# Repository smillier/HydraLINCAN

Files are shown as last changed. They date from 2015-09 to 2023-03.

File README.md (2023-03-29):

# HydraLINCAN shield for HydraBus

CAN and LIN Bus shield for Hydrabus http://hydrabus.com/
Refer to Hydrabus Wiki for more information on usage. https://github.com/hydrabus/hydrafw/wiki/HydraFW-CAN-guide



#### New version with cleaner and easier to read silkscreen.

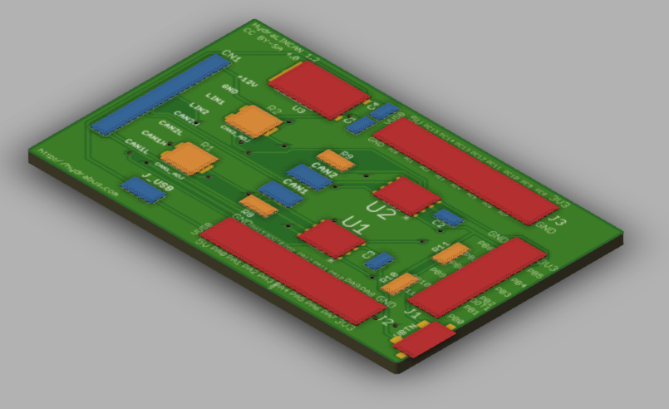
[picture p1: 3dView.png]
3DPreview


Here is the wiring schema for HydraLINCAN.

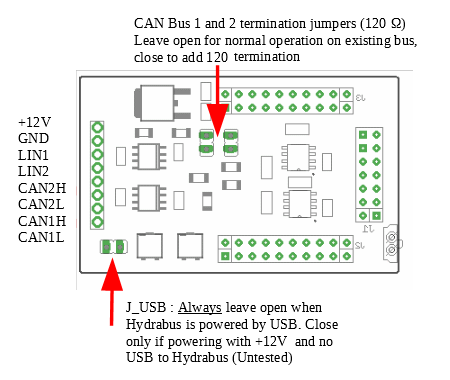
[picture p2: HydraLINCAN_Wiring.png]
HydraLINCANWiring


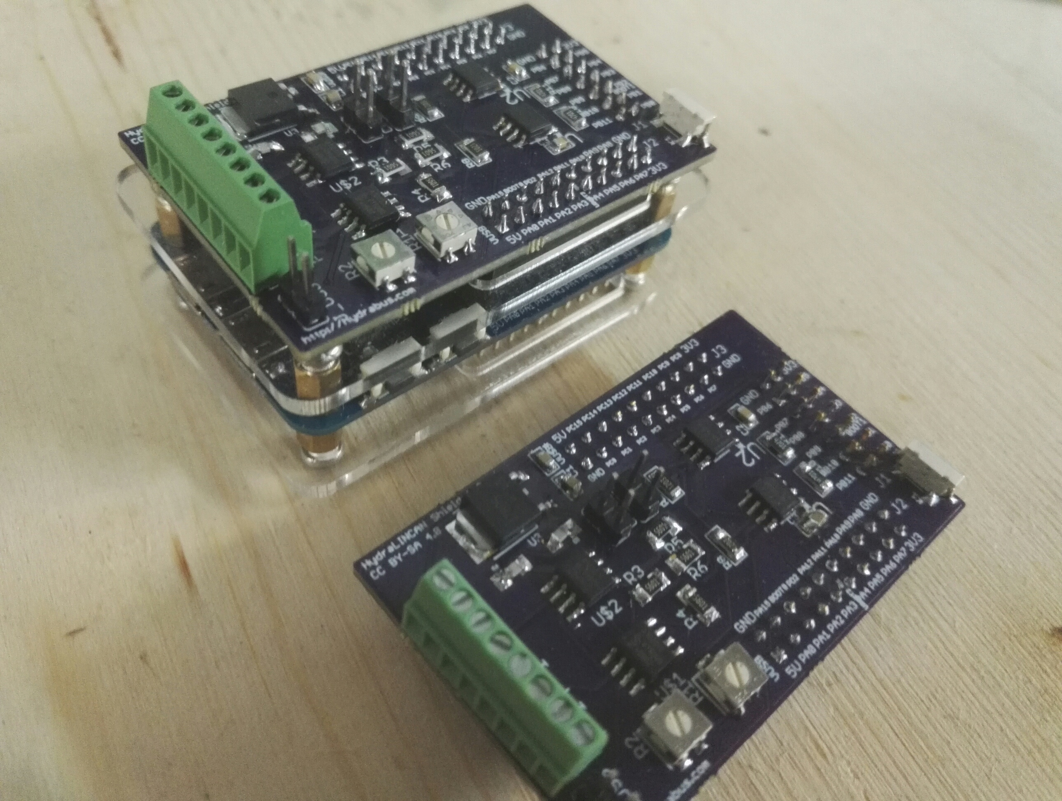
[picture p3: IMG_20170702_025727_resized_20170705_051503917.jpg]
HydraCAN


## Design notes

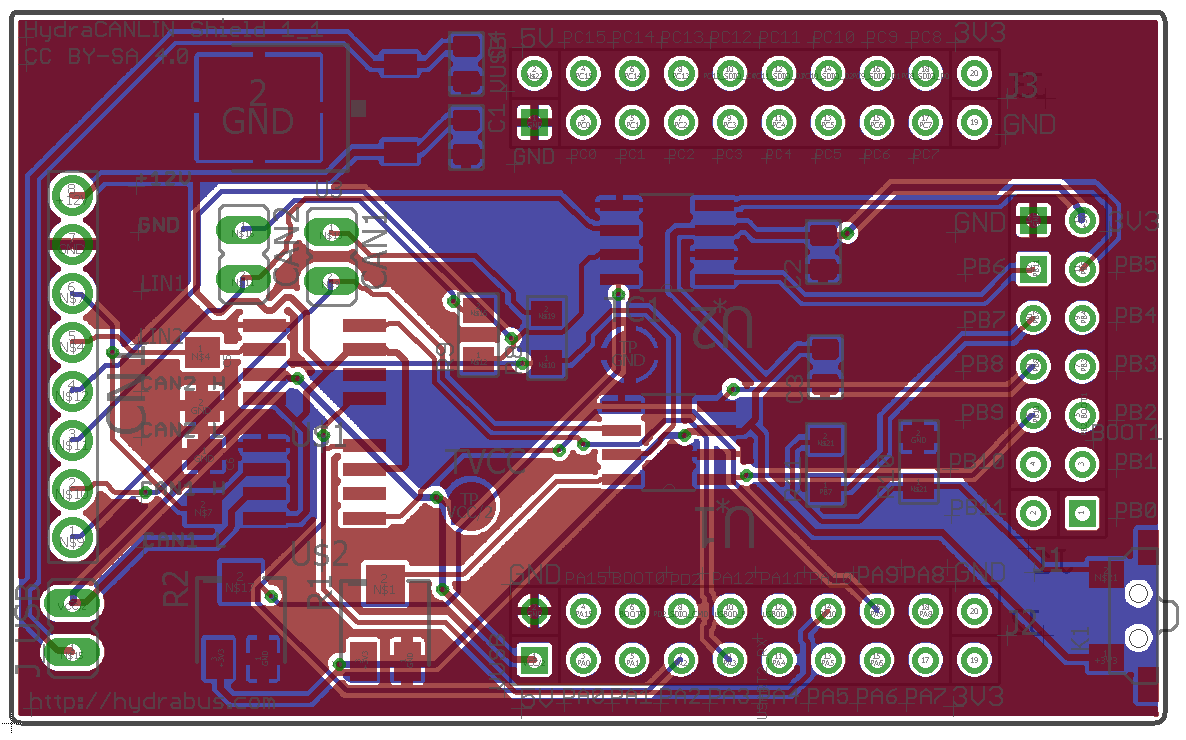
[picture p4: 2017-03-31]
HydraLINCAN.PNG

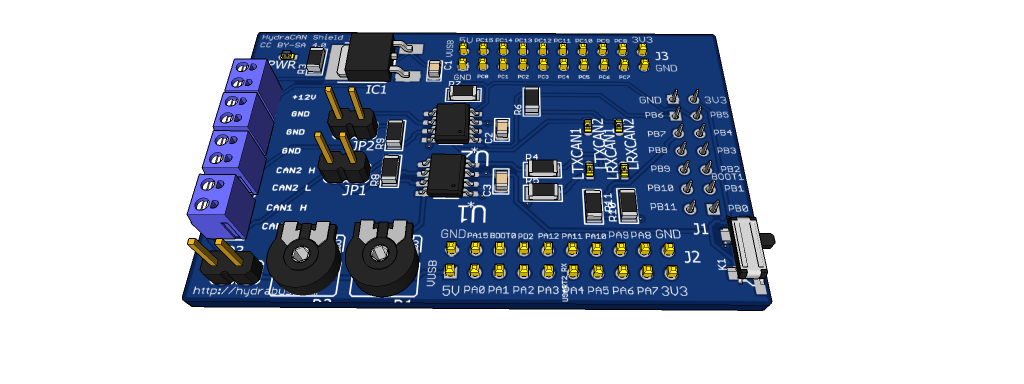
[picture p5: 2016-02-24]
hydraCanShield.png

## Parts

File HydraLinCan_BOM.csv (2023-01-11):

Part | Desc | Mouser | Digikey | LCSC
J1 | Header f2*7 | 855-M20-7830746 | S9197-ND | C124424
J2 | Header F2*10 | M20-7831046 | S9195-ND | C30867
J3 | Header F2*10 | M20-7831046 | S9195-ND | C30867
U1 | CAN SN65HVD233DG4 | 595-SN65HVD233DG4 | 296-35967-1-ND | C61643
U2 | CAN SN65HVD233DG4 | 595-SN65HVD233DG4 | 296-35967-1-ND | C61643
LIN1 | LIN TJA1021 | 771-TJA1021T10CM118 | 568-4643-1-ND | C128810
LIN2 | LIN TJA1021 | 771-TJA1021T10CM118 | 568-4643-1-ND | C128810
CN1 | Screw terminal 8p | 651-1725711 | ED10566-ND | C350883
R1 | 100K Trimmer | 652-3314J-1-104E | 3314G-104ETR-ND | C51284
R2 | 100K Trimmer | 652-3314J-1-104E | 3314G-104ETR-ND | C51284
U3 | VReg 5V | MC7805CDTG | MC7805BDTGOS-ND | C83632
R3 | R1206 4K7 | 603-RC1206FR-074K7L | CR1206-JW-472ELFCT-ND | C137262
R4 | R1206 4K7 | 603-RC1206FR-074K7L | CR1206-JW-472ELFCT-ND | C137262
R5 | R1206 4K7 | 603-RC1206FR-074K7L | CR1206-JW-472ELFCT-ND | C137262
R6 | R1206 4K7 | 603-RC1206FR-074K7L | CR1206-JW-472ELFCT-ND | C137262
R8 | R1206 120K | 667-ERJ-8GEYJ124V | CR1206-FX-1203ELFCT-ND | C163387
R9 | R1206 120K | 667-ERJ-8GEYJ124V | CR1206-FX-1203ELFCT-ND | C163387
R10 | R1206 4K7 | 603-RC1206FR-074K7L | CR1206-JW-472ELFCT-ND | C137262
R11 | R1206 4K7 | 603-RC1206FR-074K7L | CR1206-JW-472ELFCT-ND | C137262
C1 | C805 100nF/25V Electro | 81-GRM40X104K25L | 311-1456-6-ND | C396718
C2 | 100nF | 80-C0805C104J5RAUTO | 311-1456-6-ND | C396718
C3 | 100nF | 80-C0805C104J5RAUTO | 311-1456-6-ND | C396718
C4 | C805 33nF/16V Electro | GCM155R71E333KA55D | 311-3391-6-ND | C77016
C5 | 33nF | 810-C2012C0G1E333J | 311-3391-6-ND | C77016
C6 | 33nF | 810-C2012C0G1E333J | 311-3391-6-ND | C77016
C9 | 100nF | 80-C0805C104J5RAUTO | 311-1456-6-ND | C111492
C10 | 100nF | 80-C0805C104J5RAUTO | 311-1456-6-ND | C111492
C11 | 100nF | 80-C0805C104J5RAUTO | 311-1456-6-ND | C111492
C12 | 100nF | 80-C0805C104J5RAUTO | 311-1456-6-ND | C111492
K1 | SMD Push button

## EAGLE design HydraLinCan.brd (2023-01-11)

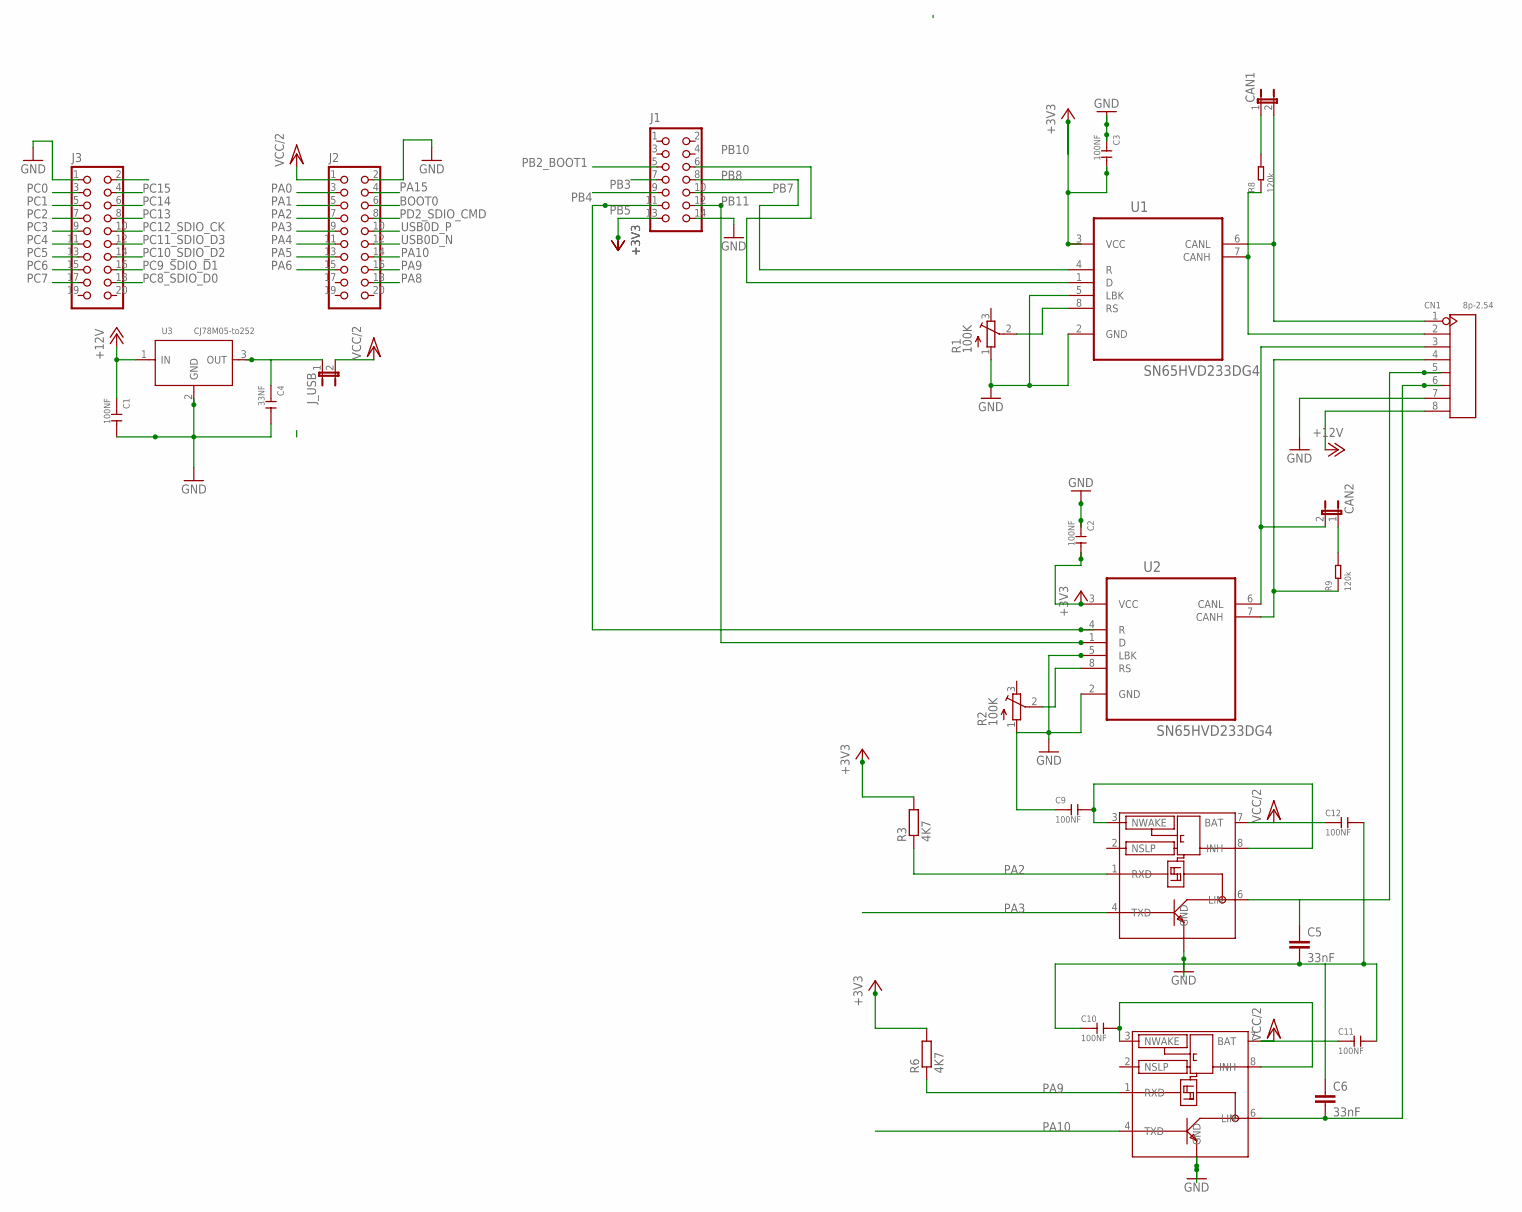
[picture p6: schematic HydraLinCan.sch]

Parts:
C1, C2, C3, C9, C10, C11, C12: 100NF; C0805
C4: 33NF; C0805
C5, C6: 33nF; 1206
CAN1, CAN2: JP1E; JP1
CN1: 8p-2.54; H8-2.54
J1: HYDRABUS_SHIELD_CON_HEADER_2X07; HYDRABUS_SHIELD_M2X7
J2, J3: HYDRABUS_SHIELD_CON_HEADER_2X10; HYDRABUS_SHIELD_M2X10
J_USB: JP1E; JP1
LIN1, LIN2: TJA1021SO8; SO8
R1, R2: 100K; SM-42/43A
R3, R6: 4K7; M1206
R8, R9: 120k; R1206
U1, U2: SN65HVD233DG4; SOIC127P600X175-8N
U3: CJ78M05-to252; TO-252

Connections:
+3V3: C2.2, C3.2, J1.13, R3.2, R6.2, U1.3 (VCC), U2.3 (VCC)
+12V: C1.1, CN1.8, U3.1 (IN)
BOOT0: J2.6
CAN1_N: CAN1.2, CN1.1, U1.6 (CANL)
CAN1_P: CN1.2, R8.1, U1.7 (CANH)
CAN2_N: CAN2.2, CN1.3, U2.6 (CANL)
CAN2_P: CN1.4, R9.1, U2.7 (CANH)
GND: C1.2, C2.1, C3.1, C4.2, C5.2, C6.1, C10.1, C11.2, C12.2, CN1.7, J1.14, J2.2, J3.1, LIN1.5 (GND), LIN2.5 (GND), R1.1 (A), U1.2 (GND), U1.5 (LBK), U2.5 (LBK), U3.2 (GND)
unnamed: R1.2 (S), U1.8 (RS)
unnamed: C5.1, CN1.5, LIN1.6 (LIN)
unnamed: C6.2, CN1.6, LIN2.6 (LIN)
unnamed: C9.2, LIN1.3 (NWAKE), LIN1.8 (INH)
unnamed: C10.2, LIN2.3 (NWAKE), LIN2.8 (INH)
unnamed: C9.1, R2.1 (A), U2.2 (GND)
unnamed: C4.1, J_USB.1, U3.3 (OUT)
unnamed: CAN2.1, R9.2
unnamed: R2.2 (S), U2.8 (RS)
unnamed: CAN1.1, R8.2
PA0: J2.3
PA1: J2.5
PA2: J2.7, LIN1.1 (RXD), R3.1
PA3: J2.9, LIN1.4 (TXD)
PA4: J2.11
PA5: J2.13
PA6: J2.15
PA8: J2.18
PA9: J2.16, LIN2.1 (RXD), R6.1
PA10: J2.14, LIN2.4 (TXD)
PA15: J2.4
PB2_BOOT1: J1.5
PB3: J1.7
PB4: J1.9
PB5: J1.11, U2.4 (R)
PB7: J1.10
PB8: J1.8, U1.4 (R)
PB10: J1.6, U1.1 (D)
PB11: J1.12, U2.1 (D)
PC0: J3.3
PC1: J3.5
PC2: J3.7
PC3: J3.9
PC4: J3.11
PC5: J3.13
PC6: J3.15
PC7: J3.17
PC8_SDIO_D0: J3.18
PC9_SDIO_D1: J3.16
PC10_SDIO_D2: J3.14
PC11_SDIO_D3: J3.12
PC12_SDIO_CK: J3.10
PC13: J3.8
PC14: J3.6
PC15: J3.4
PD2_SDIO_CMD: J2.8
USB0D_N: J2.12
USB0D_P: J2.10
VCC/2: C11.1, C12.1, J2.1, J_USB.2, LIN1.7 (BAT), LIN2.7 (BAT)

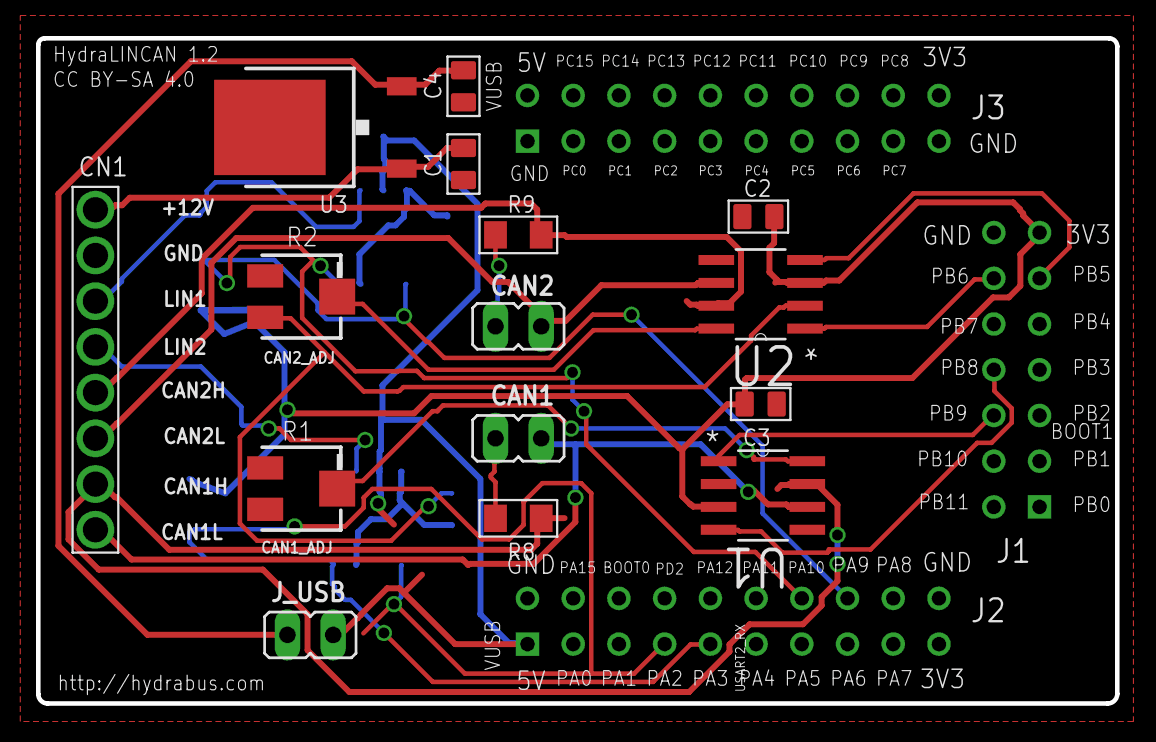
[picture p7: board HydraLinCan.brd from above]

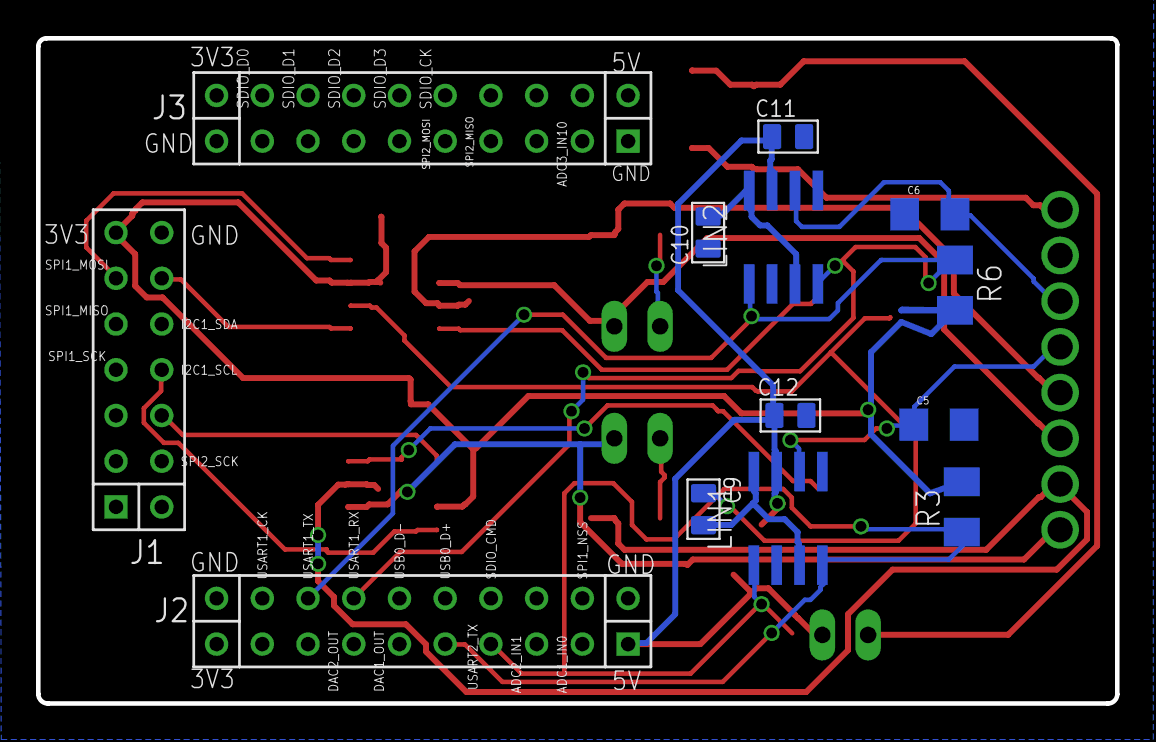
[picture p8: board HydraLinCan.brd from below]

Board: 2 copper layers, 59.9 x 37.0 mm, 28 parts (10 on the bottom side), 26 nets.

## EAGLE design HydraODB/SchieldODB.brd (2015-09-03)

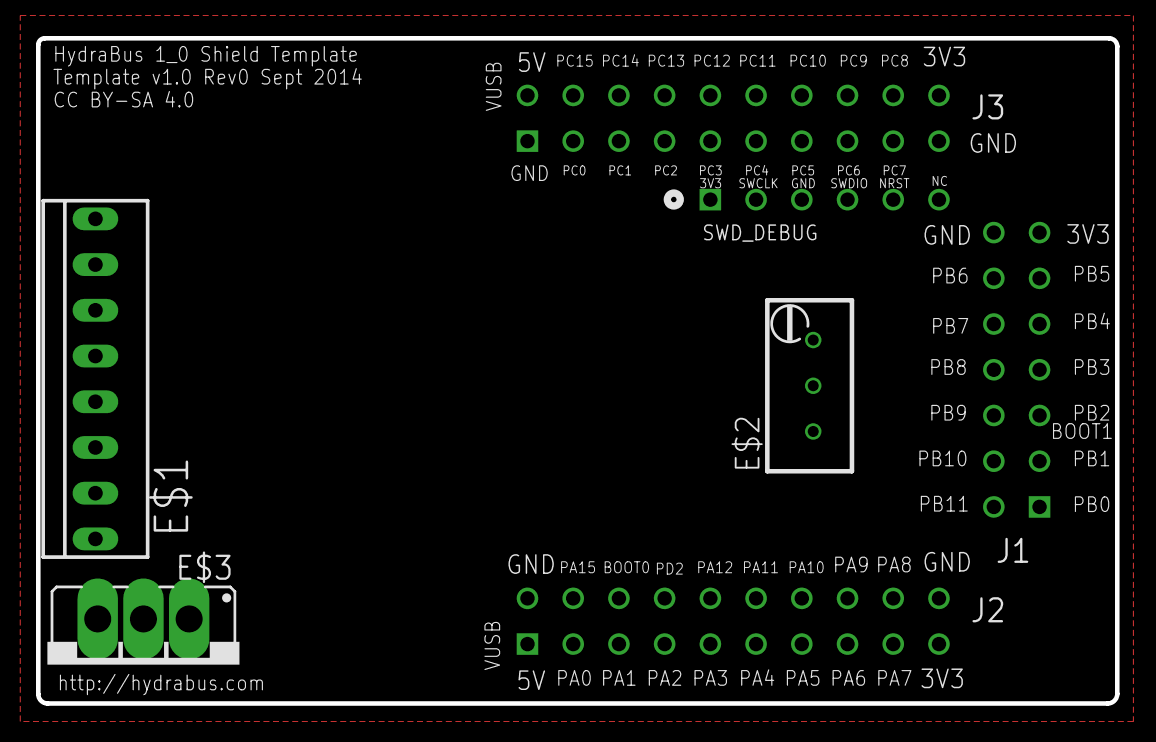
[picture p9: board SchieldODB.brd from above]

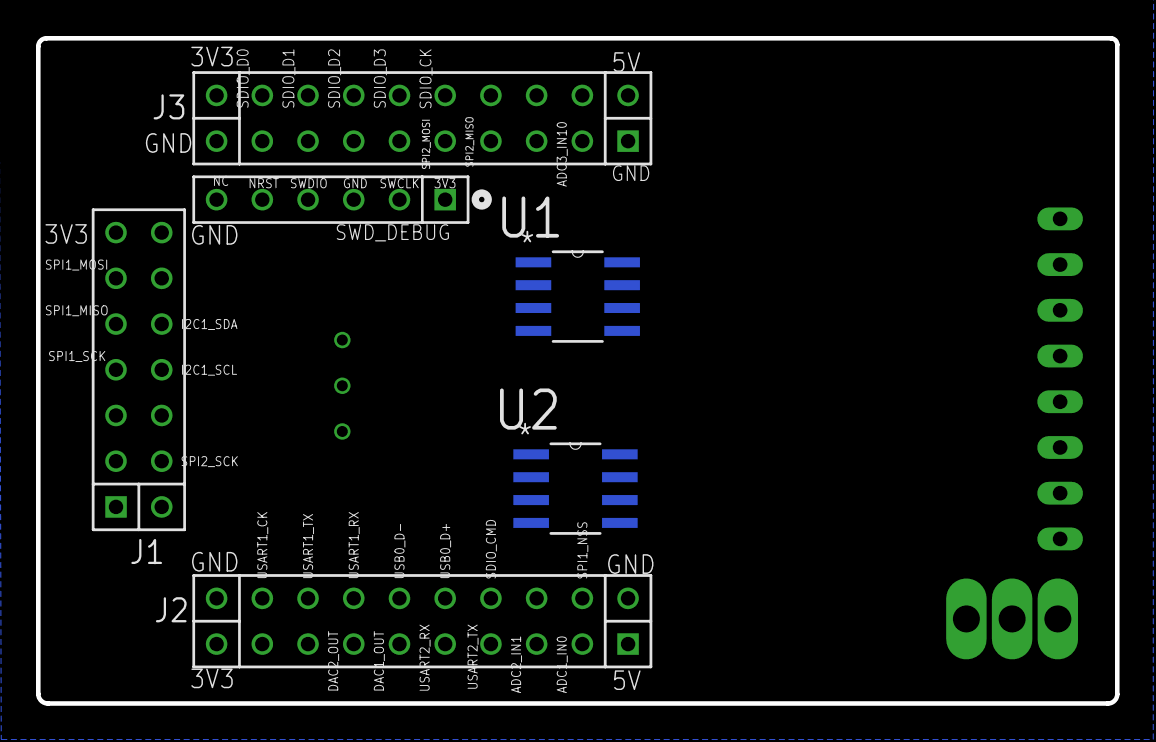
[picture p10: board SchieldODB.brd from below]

Board: 2 copper layers, 59.9 x 37.0 mm, 9 parts (2 on the bottom side), 3 nets, no tracks yet.

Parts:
E$1: 741256-49
E$2: RTRIMT93YA
E$3: 79XXS_
J1: HYDRABUS_SHIELD_CON_HEADER_2X07; HYDRABUS_SHIELD_M2X7
J2, J3: HYDRABUS_SHIELD_CON_HEADER_2X10; HYDRABUS_SHIELD_M2X10
SWD_DEBUG: HYDRABUS_SHIELD_CON_HEADER_1X06; HYDRABUS_SHIELD_M1X6
U1, U2: SN65HVD233D; SOIC127P600X175-8N

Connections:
+3V3: J1.13, J2.19, J3.20, SWD_DEBUG.1, U2.3
GND: J1.14, J2.2, J2.20, J3.1, J3.19, SWD_DEBUG.3, U1.2, U1.8, U2.2, U2.8
VUSB: J2.1, J3.2

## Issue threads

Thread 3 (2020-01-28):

Are these boards available for purchase somewhere?

mrspirytus, 2020-01-28:
Do you take orders for prebuilt boards? I see that they were available at some point. If so how where can I get one vs building myself if possible.

smillier, 2020-01-29:
I don't have anymore prebuilt boards, but let me check in the next few days if I still have some pcbs, and parts to build one. I'll get back to you asap.

mrspirytus, 2020-01-29:
Very nice. I was looking for two but one would be great too

mrspirytus, 2020-01-30:
If it is too much problem I can bUild it myself. Are latest PCB layout files and BOM are the latest?
Which service did you use to make these pubs that you were happy with?

smillier, 2020-01-30:
No, they don't support CAN FD. Only CAN classic.

mrspirytus, 2020-02-04:
Hello, just want to check if you will be able to make a board for purchase or should I start building myself? Also wondering why you stopped making them? From my search there are quite few people looking for CAN solutions.

smillier, 2020-02-14:
I've built a few ones for friends in the past, but never made any real production.
I'm making a new version of the PCB, I have quotes in progress to make it produced, this should come quick. I'll be able to provide you one.
If everything is OK with this new ones, I should be able to produce small quantities of this board.
Keep you in touch.

mrspirytus, 2020-02-14:
Excellent....

smillier, 2020-02-14:
What new hydra board are you talking about ? There is an HydraNFC v2 in progress, it's a shield, not an Hydrabus. There are a few revisions of the Hydrabus hardware, but no major version to come as far as I know.
HydraLinCan is a shield meant to be used with Hydrabus, should it be old or new version, it's will be 100% compatible.

smillier, 2020-02-14:
> Excellent....
> BTW they should be 100% backward compatible to new upcoming hydra board I am reading on Twitter?

How many HydraLINCAN boards would you need ?

mrspirytus, 2020-02-14:
> What new hydra board are you talking about ? There is an HydraNFC v2 in progress, it's a shield, not an Hydrabus. There are a few revisions of the Hydrabus hardware, but no major version to come as far as I know.
> HydraLinCan is a shield meant to be used with Hydrabus, should it be old or new version, it's will be 100% compatible.

Perhaps it is NFC only and not the hydra bus itself. It indeed it is NFC only change then disregard my question :)

mrspirytus, 2020-02-14:
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

Possibly two. What is the price?  PayPal when ready?

smillier, 2020-02-14:
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

So I'll send you two boards. Quotes are still in progress for production, I'll get back to you when ready. Paypal is fine.

smillier, 2020-02-15:
I have news for you. Can you give me your email address or do you have a Slack account so we can discuss?
https://join.slack.com/t/smillier/shared_invite/enQtOTU2MDI0MTAzMjg3LTExNTVkOWI3ODdhZjE2ZTg0YTY4YWM1NTI5M2Y1ZGJlZTVmMWY4MmU5ODg1YmJjM2FlMWE3YjQ5MWVhNDg5Zjc

mrspirytus, 2020-02-15:
mrspirytus@yahoo.com

smillier, 2020-02-15:
.com or anything else ? I get an email not found

mrspirytus, 2020-02-15:
mr.spirytus at yahoo dot com
Sorry about the missing dot

mrspirytus, 2020-02-15:
Please send me slack link again please. I did not save it. You can remove it as soon as I sign up.

mrspirytus, 2020-09-13:
Hello,

Long time I did not hear from you. I was wondering if you still have some boards I could get from you. I did try to text you to the number you gave me while back butt, I did not hear from you.

Please let me know if you have any boards. Or if you could recommend a place where you printed your boards and I get parts myself and put a few together.

Cheers

Robert

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

TechLobo, 2022-07-11:
> Hello, Long time I did not hear from you. I was wondering if you still have some boards I could get from you. I did try to text you to the number you gave me while back butt, I did not hear from you. Please let me know if you have any boards. Or if you could recommend a place where you printed your boards and I get parts myself and put a few together. Cheers Robert
> […](#)
> On Jan 29, 2020, at 02:25, smillier ***@***.***> wrote: I don't have anymore prebuilt boards, but let me check in the next few days if I still have some pcbs, and parts to build one. I'll get back to you asap. — You are receiving this because you authored the thread. Reply to this email directly, view it on GitHub <#3?email_source=notifications&email_token=AOMXYEDQV7KP77LK3O7YF7TRAE4RBA5CNFSM4KMRWRAKYY3PNVWWK3TUL52HS4DFVREXG43VMVBW63LNMVXHJKTDN5WW2ZLOORPWSZGOEKGLMOQ#issuecomment-579647034>, or unsubscribe <https://github.com/notifications/unsubscribe-auth/AOMXYEHFRXKSQBJZQHYVOHLRAE4RBANCNFSM4KMRWRAA>.

Did you ever create some boards?

Closed 2020-02-15.

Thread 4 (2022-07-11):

Prebuilt board availability?

TechLobo, 2022-07-11:
I note that there is a closed issue regarding this topic that did not appear to have a fulfilled resolution.

I too am interested whether there are prebuilt / tested boards available for purchase, and how much they cost?

mrspirytus, 2022-11-11:
+1

smillier, 2022-11-17:
I'm planning to make a new batch of boards. Let me know if  still interested

mrspirytus, 2022-11-18:
I am interested. Two hat’s

TechLobo, 2022-11-18:
Depends on price. As there was no response earlier I had to go a different route, and now you can't buy the Hydrabus board!

smillier, 2022-11-26:
> Depends on price. As there was no response earlier I had to go a different route, and now you can't buy the Hydrabus board!

50€ / shield,  I will see if  I can have contact for the Hydrabus avalaibility.

smillier, 2022-11-26:
> I am interested. Two hat’s

noted, will do my best

bvernoux, 2022-11-27:
> > Depends on price. As there was no response earlier I had to go a different route, and now you can't buy the Hydrabus board!
>
> 50€ / shield, I will see if I can have contact for the Hydrabus avalaibility.

For information HydraBus v1 boards will be available in December 2022 at DigiKey
For information all information related to HydraBus products are available online https://hydrabus.com/buy-online

mrspirytus, 2022-11-27:
Any general ETA about prebuilt boards?

smillier, 2023-01-12:
> Any general ETA about prebuilt boards?

It's been ordered today, will keep you informed of ETA.

mrspirytus, 2023-01-13:
Awesome :) just wondering, any hardware updates from original batch? Or another run for same hardware versions. (Component shortage)

smillier, 2023-02-24:
Pre-built boards are back in stock. PM me for to get them.

smillier, 2023-02-27:
> Pre-built boards are back in stock. PM me for to get them.

mrspirytus, 2023-03-10:
Got a link to place the order? How much per unit?

smillier, 2023-03-18:
> Got a link to place the order? How much per unit?

I'm trying to make it available on Tindie, but you can send me email. sylvain.millier@gmail.com

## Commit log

2015-08-27 Eagle Project
    [SchieldODB.brd, SchieldODB.sch]
2015-09-03 Schema and board corrections
    [SchieldODB.brd, SchieldODB.sch]
2015-09-16 VReg add, CanBus 2 rewired
    [SchieldODB.sch]
2015-09-16 Schema redisign
    [SchieldODB.sch]
2015-10-07 Rebuilt everything, schema and board were inconsistent. First try at PCB routing.
    [OBDShield.brd, OBDShield.sch]
2015-10-07 board pcb routing tryout
    [OBDShield.brd]
2015-10-12 Placing and routing
    [OBDShield.brd, OBDShield.sch]
2015-10-13 Proto pcb routing
    Routing signle layer for proto pcb
    [OBDShield.brd, OBDShield.sch]
2015-10-13 Schema correction
    [OBDShield.brd, OBDShield.sch]
2015-10-16 2 Layers PCB
    [OBDShield-2layers.brd, OBDShield-2layers.sch]
2015-11-17 Corrected J2 mirror
    [OBDShield-2layers.brd, OBDShield-2layers.sch, OBDShield.brd]
2015-11-17 Upload gerber for 1 layer pcb
    [shield.gbr]
2015-11-19 CleanUp - Start over from 2 layers shield
    [OBDShield-2layers.brd, OBDShield-2layers.sch, OBDShield.brd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]
2015-11-19 Mistake :-D
    [OBDShield.brd, OBDShield.sch]
2015-11-19 Decoupling caps, user button and different mistakes
    [OBDShield.brd, OBDShield.sch]
2015-11-22 GBR updated
    [shield.gbr]
2015-11-24 Different corrections and missing wire
    [OBDShield.brd, OBDShield.sch]
2015-11-25 Decap condos
    [OBDShield.brd, OBDShield.sch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]
2015-11-30 Updated board
    [OBDShield.brd]
2016-02-22 Board modifications, silk screen
    Still some work to do on the board
    [OBDShield.brd, OBDShield.sch]
2016-02-23 Solved files merging pb.
    [OBDShield.brd, OBDShield.sch]
2016-02-24 Power changed and jumper added, packages changed, inverted can h/l on silk
    [OBDShield.brd, OBDShield.sch]
2016-02-28 OBD Connector corrected, VReg changed, Routing modification and smd packages corrected
    [OBDShield.brd, OBDShield.sch]
2016-06-07 final working routing,
    [OBDShield.brd, OBDShield.sch]
2017-03-30 Added 2 LIN Bus transceivers
    [OBDShield.brd, OBDShield.sch]
2017-03-31 PCB preview
2017-03-31 Pullups for LIN transceivers
    [OBDShield.brd, OBDShield.sch]
2017-05-03 Routing corrections
    [OBDShield.brd, OBDShield.sch]
2017-05-04 corrections on ground plate
    [OBDShield.brd, OBDShield.sch]
2017-08-29 Corrections for CAN and LIN buses
    Deleted connections between trimmers and VCC
    Added decap on LIN tranceivers
    [OBDShield.sch]
2017-09-04 routing improvements
    Via size increased, manual can traces routes, decap routed correctly. Should be ready for fab, BOM still to come
    [OBDShield_route3.brd, OBDShield_route3.sch]
2017-10-05 Routing corrections + Mouser BOM
    [BOM_Mouser - Sheet1.csv, HydraLinCan.brd, HydraLinCan.sch]
2017-11-08 BOM Optimazation and DigiKey Refs
    BOM Optimazation and DigiKey Refs
    [HydraLinCan_BOM.csv]
2018-01-19 Wiring HydraLINCAN board
2018-01-19 Update wiring schema
2019-08-25 Add LCSC parts
    [HydraLinCan_BOM.csv]
2020-02-03 2 layers parts
    [HydraLinCan.brd, HydraLinCan.sch]
2020-02-03 Routing CAN H/L as real diff pairs
    [HydraLinCan.brd]
2020-02-11 Silkscreen cleaning
    [HydraLinCan.brd, HydraLinCan.sch]
2020-02-12 Typo 120K -> 120 bus termination resistor
2023-01-11 Upgrade LIN transceivers for LIN2.0-2.2A/SAE J2602 and ISO 17984-4 compatibility
    [HydraLinCan.brd, HydraLinCan.sch, HydraLinCan_BOM.csv]

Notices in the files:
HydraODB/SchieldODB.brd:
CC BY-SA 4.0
